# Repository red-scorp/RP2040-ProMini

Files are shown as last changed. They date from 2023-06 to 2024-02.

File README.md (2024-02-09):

```
 ______  ______ ______   ______   __     ______     ______           ______  _       _ 
(_____ \(_____ (_____ \ / __   | / /    / __   |   (_____ \         |  ___ \(_)     (_)
 _____) )_____) )____) ) | //| |/ /____| | //| |___ _____) )___ ___ | | _ | |_ ____  _ 
(_____ (|  ____//_____/| |// | |___   _) |// | (___)  ____/ ___) _ \| || || | |  _ \| |
      | | |     _______|  /__| |   | | |  /__| |   | |   | |  | |_| | || || | | | | | |
      |_|_|    (_______)\_____/    |_|  \_____/    |_|   |_|   \___/|_||_||_|_|_| |_|_|
```

# RP2040-ProMini Project

The RP2040-ProMini project aims to create a replacement for the Arduino Pro Mini using the RP2040 MCU.

## RP2040-ProMini Board

The **RP2040-ProMini** board is a 4-layer board designed to accommodate the popular Raspberry Pi RP2040 MCU in the commonly used, but obsolete, Arduino Pro Mini footprint.

Preview:

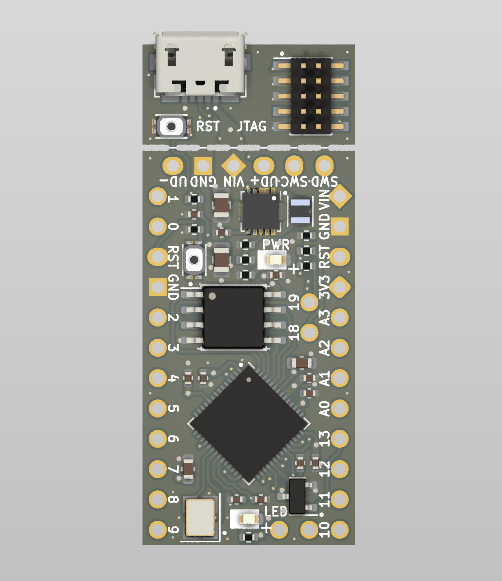
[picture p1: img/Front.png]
RP2040-ProMini Front preview

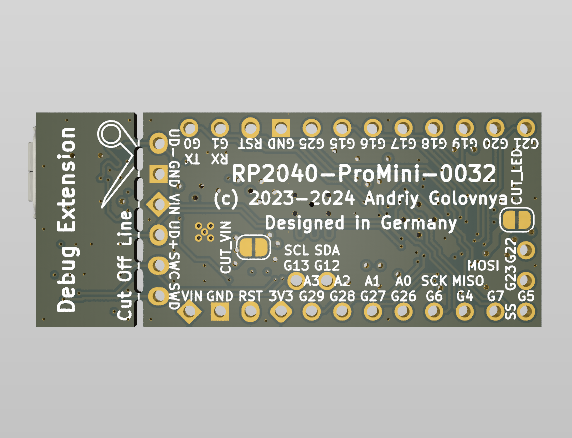
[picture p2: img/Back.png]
RP2040-ProMini Back preview

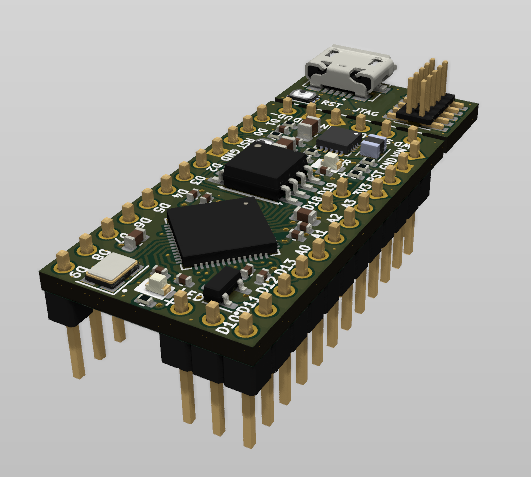
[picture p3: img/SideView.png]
RP2040-ProMini Side View preview


You can view the [Schematics in PDF format](doc/RP2040-ProMini.pdf) for detailed information.

STEP 3D files are available [with pins](doc/RP2040-ProMini-with-pins.step) and [without pins](doc/RP2040-ProMini-board.step).

Features:

- Arduino Pro Mini compatible pinout
- Partially compatible with Arduino Nano RP2040 Connect pinout
- _(v3.x)_ Detachable USB and JTAG extension board with RESET button
- Dual-core Cortex-M0+ Raspberry Pi RP2040
- Small footprint suitable for DIY projects
- _(v1.x)_ 19 GPIO pins, including 4 analog inputs or _(v2.x-v3.x)_ 21 GPIO pins, including 4 analog inputs
- USB data pins on the side connector
- SWD debugging pins on the side connector
- _(v1.x)_ LDO-based 3.3V power supply with a maximum 16V input or _(v2.x-v3.x)_ Buck-Boost converter based 3.3V power supply with input range of 2.5V-12V
- Supports both SOIC and WSON 16MB flash packages
- Flat back side enables use as a sub-assembly
- Two cut points to reduce power consumption of unused components

CAM files, as well as the BOM and CPL files for JLCPCB, are available.

### Board Pinout

Following pinout is used for the board:

| Board Pin | RP2040 Pin | Function | Notes |
| --- | --- | --- | ----- |
| D0 | GPIO1 | UART0 TX | |
| D1 | GPIO0 | UART0 RX | |
| D2 | GPIO25 | | |
| D3 | GPIO15 | | |
| D4 | GPIO16 | | |
| D5 | GPIO17 | | |
| D6 | GPIO18 | | |
| D7 | GPIO19 | | |
| D8 | GPIO20 | | |
| D9 | GPIO21 | | |
| D10 | GPIO5 | SS | |
| D11 | GPIO7 | MOSI | |
| D12 | GPIO4 | MISO | |
| D13 | GPIO6 | SCK | LED |
| D14 A0 | GPIO26 | | |
| D15 A1 | GPIO27 | | |
| D16 A2 | GPIO28 | | |
| D17 A3 | GPIO29 | | |
| D18 | GPIO12 | SDA | |
| D19 | GPIO13 | SCL | |
| D20 | GPIO22 | | |
| D21 | GPIO23 | | |

### Cut Points

There are two cut points on the board to reduce power consumption of unused components.

| Cut Point | Function | Notes |
| --- | --- | ----- |
| CUT_VIN | Separates VIN-to-3V3 power supply with power LED from the rest of the board | This cut point is useful if you want to power the board from 3V3 pin instead of VIN pin. |
| CUT_LED | Separates LED on pin D13 from the rest of the board | This cut point is useful if you want to reduce power consumption of the board. |

## Version History

Roughly RP2040-ProMini board exists in three flavors:

- v1.x - this boards are cheaper because they are based on LDO power supply.
- v2.x - this boards are more expensive because they are based on Buck-Boost power supply.
- v3.x - this boards has same basic design as v2.x but includes detachable USB and JTAG extension board.

The development of v3.x boards is happening in *master* branch, while v1.x and v2.x boards are developed in *dev_v1* and *dev_v2* branches respectively.

Each board version listed below is tagged in its respective branch and includes all the necessary files to manufacture the board.

### v3.2 - 09.02.2024

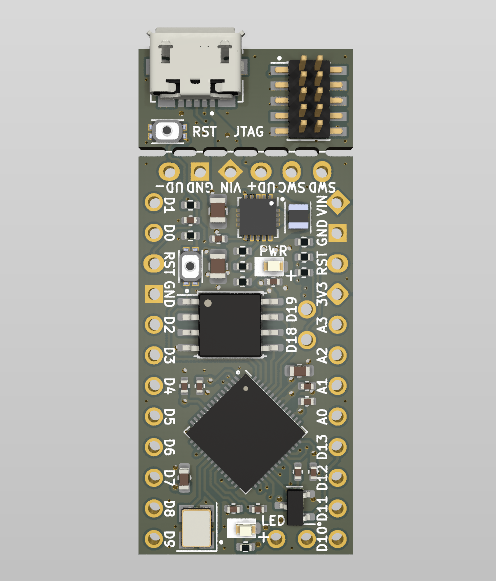
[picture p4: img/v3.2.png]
v3.2 board preview


- Added Gxx pin names on the back of the board.
- Made extension board cut-out openings wider for easier cutting.

### v3.1 - 21.11.2023

v3.1 board preview

- Removed pull-up resistor from SWCLK line.
- Added white silkscreen under LEDs to add light reflection.

### v3.0 - 29.08.2023

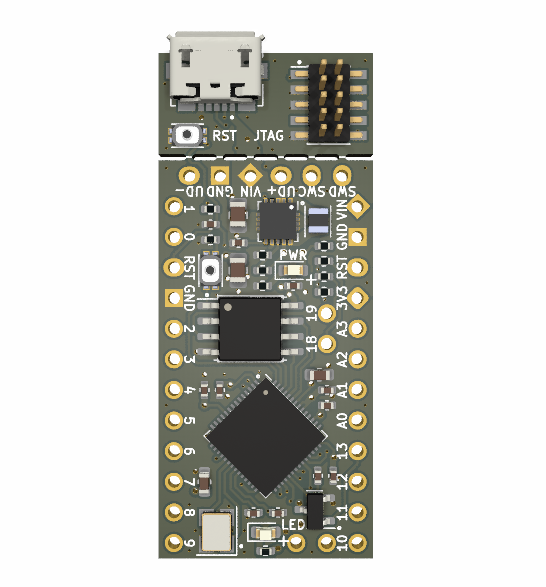
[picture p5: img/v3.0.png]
v3.0 board preview


- Added detachable USB and JTAG extension board with RESET button.
- Improved routing a bit.

### v2.2 - 01.01.2024

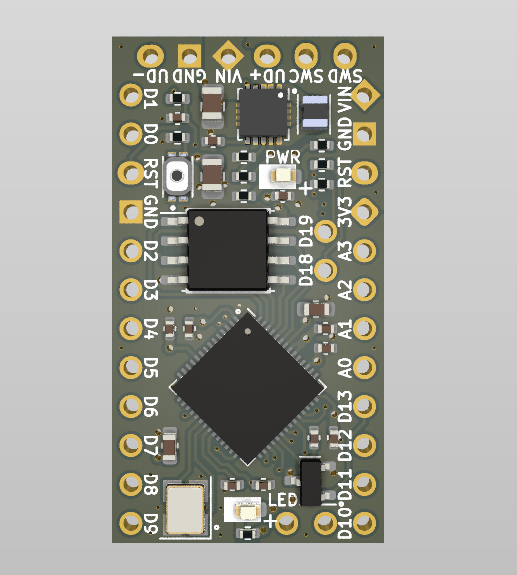
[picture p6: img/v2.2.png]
v2.2 board preview


- Added Gxx pin names on the back of the board.

### v2.1 - 21.11.2023

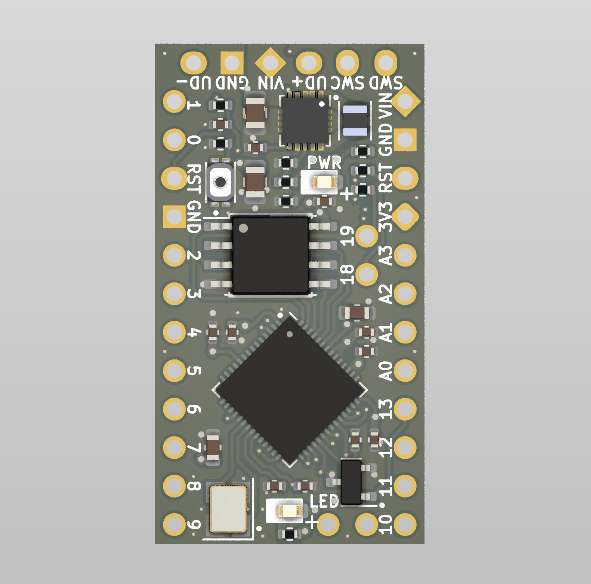
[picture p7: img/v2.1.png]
v2.1 board preview


- Removed pull-up resistor from SWCLK line.
- Added white silkscreen under LEDs to add light reflection.

### v2.0 - 23.07.2023

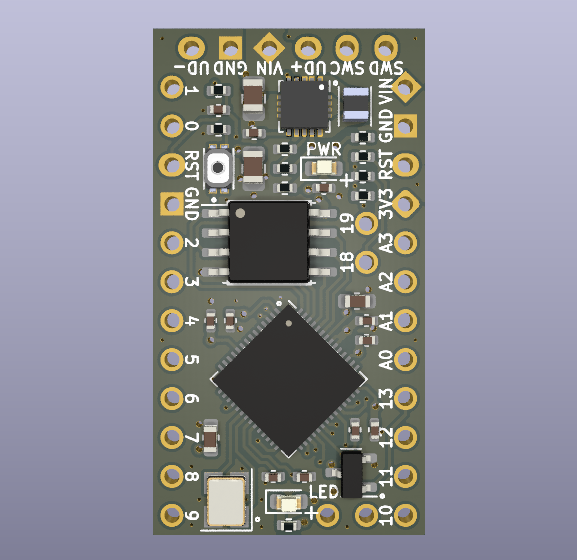
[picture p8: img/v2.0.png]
v2.0 board preview


- Use Buck-Boost converter instead of LDO.
- Added two new digital pins.
- Moved few components around.

### v1.3 - 01.01.2024

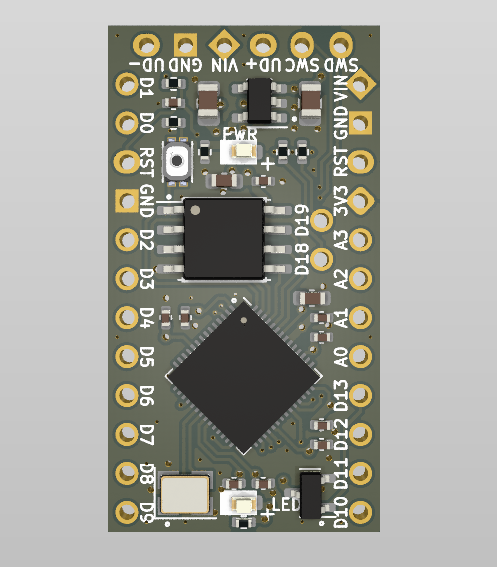
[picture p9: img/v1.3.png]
v1.3 board preview


- Added Gxx pin names on the back of the board.
- Made front and back texts bigger for better readability.

### v1.2 - 21.11.2023

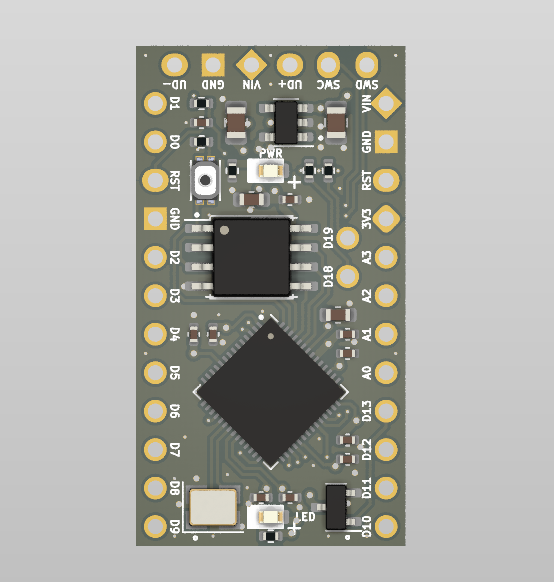
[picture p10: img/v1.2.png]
v1.2 board preview


- Removed pull-up resistor from SWCLK line.
- Added white silkscreen under LEDs to add light reflection.

### v1.1 - 05.07.2023

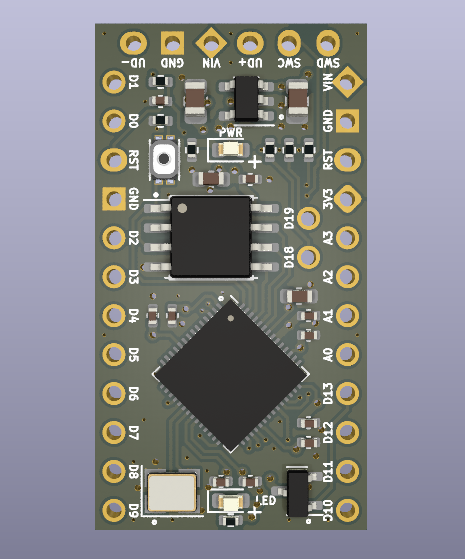
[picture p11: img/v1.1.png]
v1.1 board preview


- Moved few components around.
- Added BOOTSEL mini button for programming convenience.
- Changed LED resistors to allow more current, making LED to emit more light.

### v1.0 - 25.06.2023

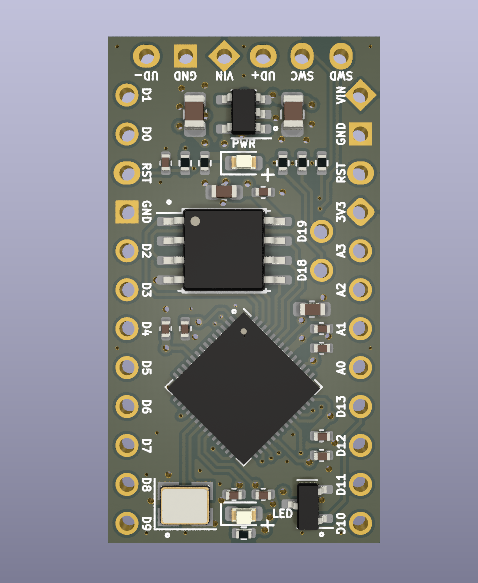
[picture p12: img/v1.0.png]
v1.0 board preview


- Moved few resistors around.
- Added small GND fill under the MCU.
- Switched positions of UD- and GND pins on the side connector.
- Generated different set of BOM and CPL files for SOIC and WSON versions of the board.

### v1.0b1 - 13.06.2023

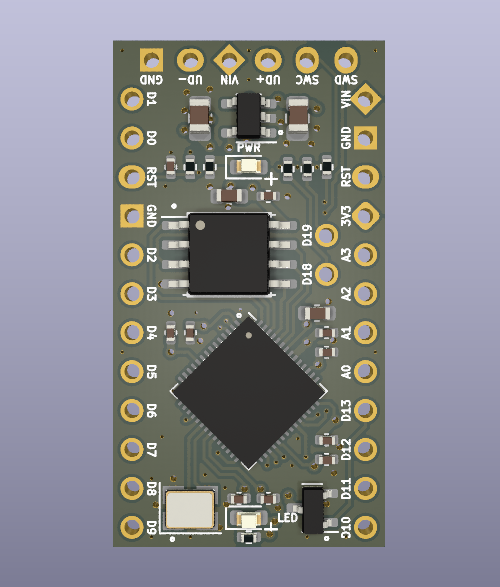
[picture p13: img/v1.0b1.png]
v1.0b1 board preview


Initial release for testing purposes.

## Links

- [Raspberry Pi RP2040 information page](https://www.raspberrypi.com/documentation/microcontrollers/rp2040.html).
- [Arduino Pro Mini information page](https://docs.arduino.cc/retired/boards/arduino-pro-mini).
- [Arduino Nano RP2040 Connect page](https://docs.arduino.cc/hardware/nano-rp2040-connect).
- [Arduino SDK for RP2040 board](https://github.com/earlephilhower/arduino-pico).

## How to Help

Your contributions as code, resources, or finances are welcome! Please contact me directly via email at andriy.golovnya@gmail.com or through my [GitHub profile](https://github.com/red-scorp).

If you'd like to make a financial contribution, you can donate via [PayPal](http://paypal.me/redscorp) or [Ko-Fi](http://ko-fi.com/redscorp). Your support is greatly appreciated.

Thanks in advance!

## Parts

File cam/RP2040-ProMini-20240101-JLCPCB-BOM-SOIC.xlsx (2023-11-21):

Qty | Designator | Footprint | JLCPCB Part# | Comment
2 | C14,C12 | 0805 | C15850 | 10uF
2 | D2,D1 | 0603 | C2286 | RED
11 | C10,C6,C7,C9,C13,C4,C2,C11,C3,C15,C8 | 0402 | C1525 | 100nF
1 | R10 | 0402 | C100271 | 174k
3 | R4,R3,R5 | 0402 | C25744 | 10k
2 | R1,R6 | 0402 | C25905 | 5k1
1 | U1 | SOIC-8-208mil | C97521 | W25Q128JVS
2 | S1,S2 | SMD,1.6x2.6mm | C913786 | 1TS026A-1800-0553-CT
1 | Y1 | SMD3225-4P | C9002 | 12MHz
1 | U2 | LQFN-56(7x7) | C2040 | RP2040
1 | Q1 | SOT-23-3L | C20917 | AO3400A
1 | R7 | 0402 | C11702 | 1k
2 | R8,R9 | 0402 | C279988 | 1M
1 | U3 | WSON-10-EP(3x3) | C48567 | TPS63060
2 | C1,C5 | 0603 | C1604 | 2.2uF
1 | L1 | 0806 | C370025 | 1.5uH
1 | J6 | SMD | C2763165 | USB B micro
1 | J7 | SMD,P=1.27mm | C598540 | JTAG

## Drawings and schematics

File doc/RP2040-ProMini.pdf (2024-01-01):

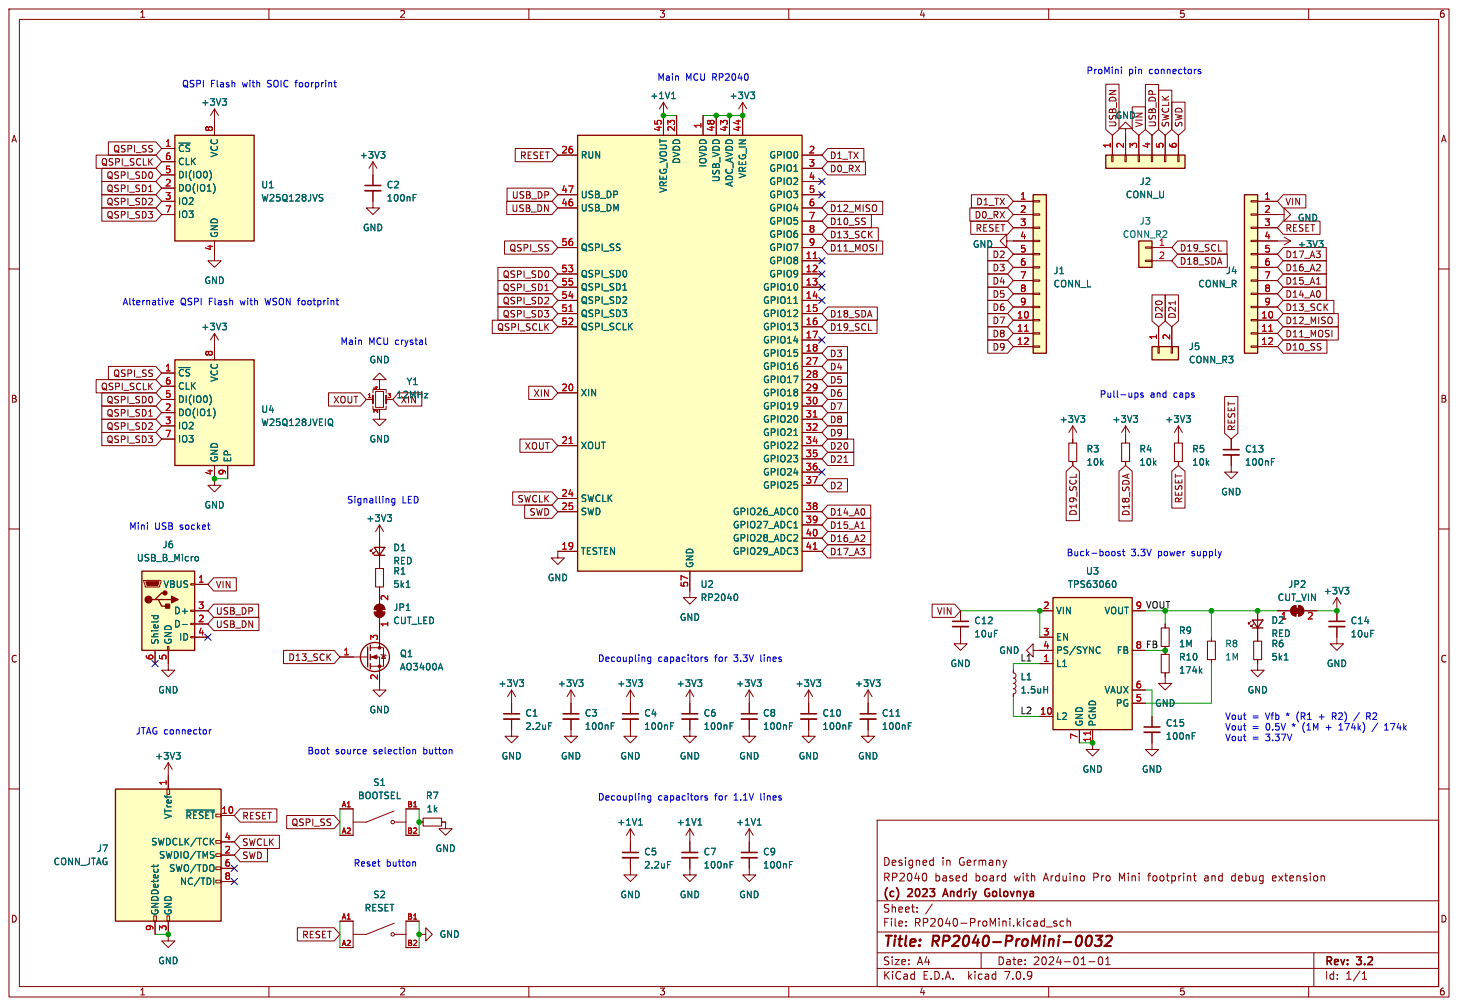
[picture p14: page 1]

1 GPIO8 11 GPIO9 12 GPIO10 13 GPIO11 14 GPIO12 15 GPIO13 16 GPIO14 17 GPIO15 18 TESTEN 19 GPIO0 2 XIN 20 XOUT 21 DVDD 23 SWCLK 24 SWD 25 RUN 26 GPIO16 27 GPIO17 28 GPIO18 29 GPIO1 3 GPIO19 30 GPIO20 31 GPIO21 32 GPIO22 34 GPIO23 35 GPIO24 36 GPIO25 37 GPIO26_ADC0 38 GPIO27_ADC1 39 GPIO2 4 GPIO28_ADC2 40 GPIO29_ADC3 41 ADC_AVDD 43 VREG_IN 44 VREG_VOUT 45 USB_DM 46 USB_DP 47 USB_VDD 48 GPIO3 5 QSPI_SD3 51 QSPI_SCLK 52 QSPI_SD0 53 QSPI_SD2 54 QSPI_SD1 55 QSPI_SS 56 GND 57 GPIO4 6 GPIO5 7 GPIO6 8 GPIO7 9 GND GND

1 GPIO8 11 GPIO9 12 GPIO10 13 GPIO11 14 GPIO12 15 GPIO13 16 GPIO14 17 GPIO15 18 TESTEN 19 GPIO0 2 XIN 20 XOUT 21 DVDD 23 SWCLK 24 SWD 25 RUN 26 GPIO16 27 GPIO17 28 GPIO18 29 GPIO1 3 GPIO19 30 GPIO20 31 GPIO21 32 GPIO22 34 GPIO23 35 GPIO24 36 GPIO25 37 GPIO26_ADC0 38 GPIO27_ADC1 39 GPIO2 4 GPIO28_ADC2 40 GPIO29_ADC3 41 ADC_AVDD 43 VREG_IN 44 VREG_VOUT 45 USB_DM 46 USB_DP 47 USB_VDD 48 GPIO3 5 QSPI_SD3 51 QSPI_SCLK 52 QSPI_SD0 53 QSPI_SD2 54 QSPI_SD1 55 QSPI_SS 56 GND 57 GPIO4 6 GPIO5 7 GPIO6 8 GPIO7 9 U2 RP2040 GND

8 U1 W25Q128JVS GND GND GND GND

Vout = Vfb * (R1 + R2) / R2 Vout = 0.5V * (1M + 174k) / 174k Vout = 3.37V Main MCU crystal
GND

3 SWDCLK/TCK 4 SWO/TDO 6 NC/TDI 8 GNDDetect 9

3 SWDCLK/TCK 4 SWO/TDO 6 NC/TDI 8 GNDDetect 9 GND GND GND

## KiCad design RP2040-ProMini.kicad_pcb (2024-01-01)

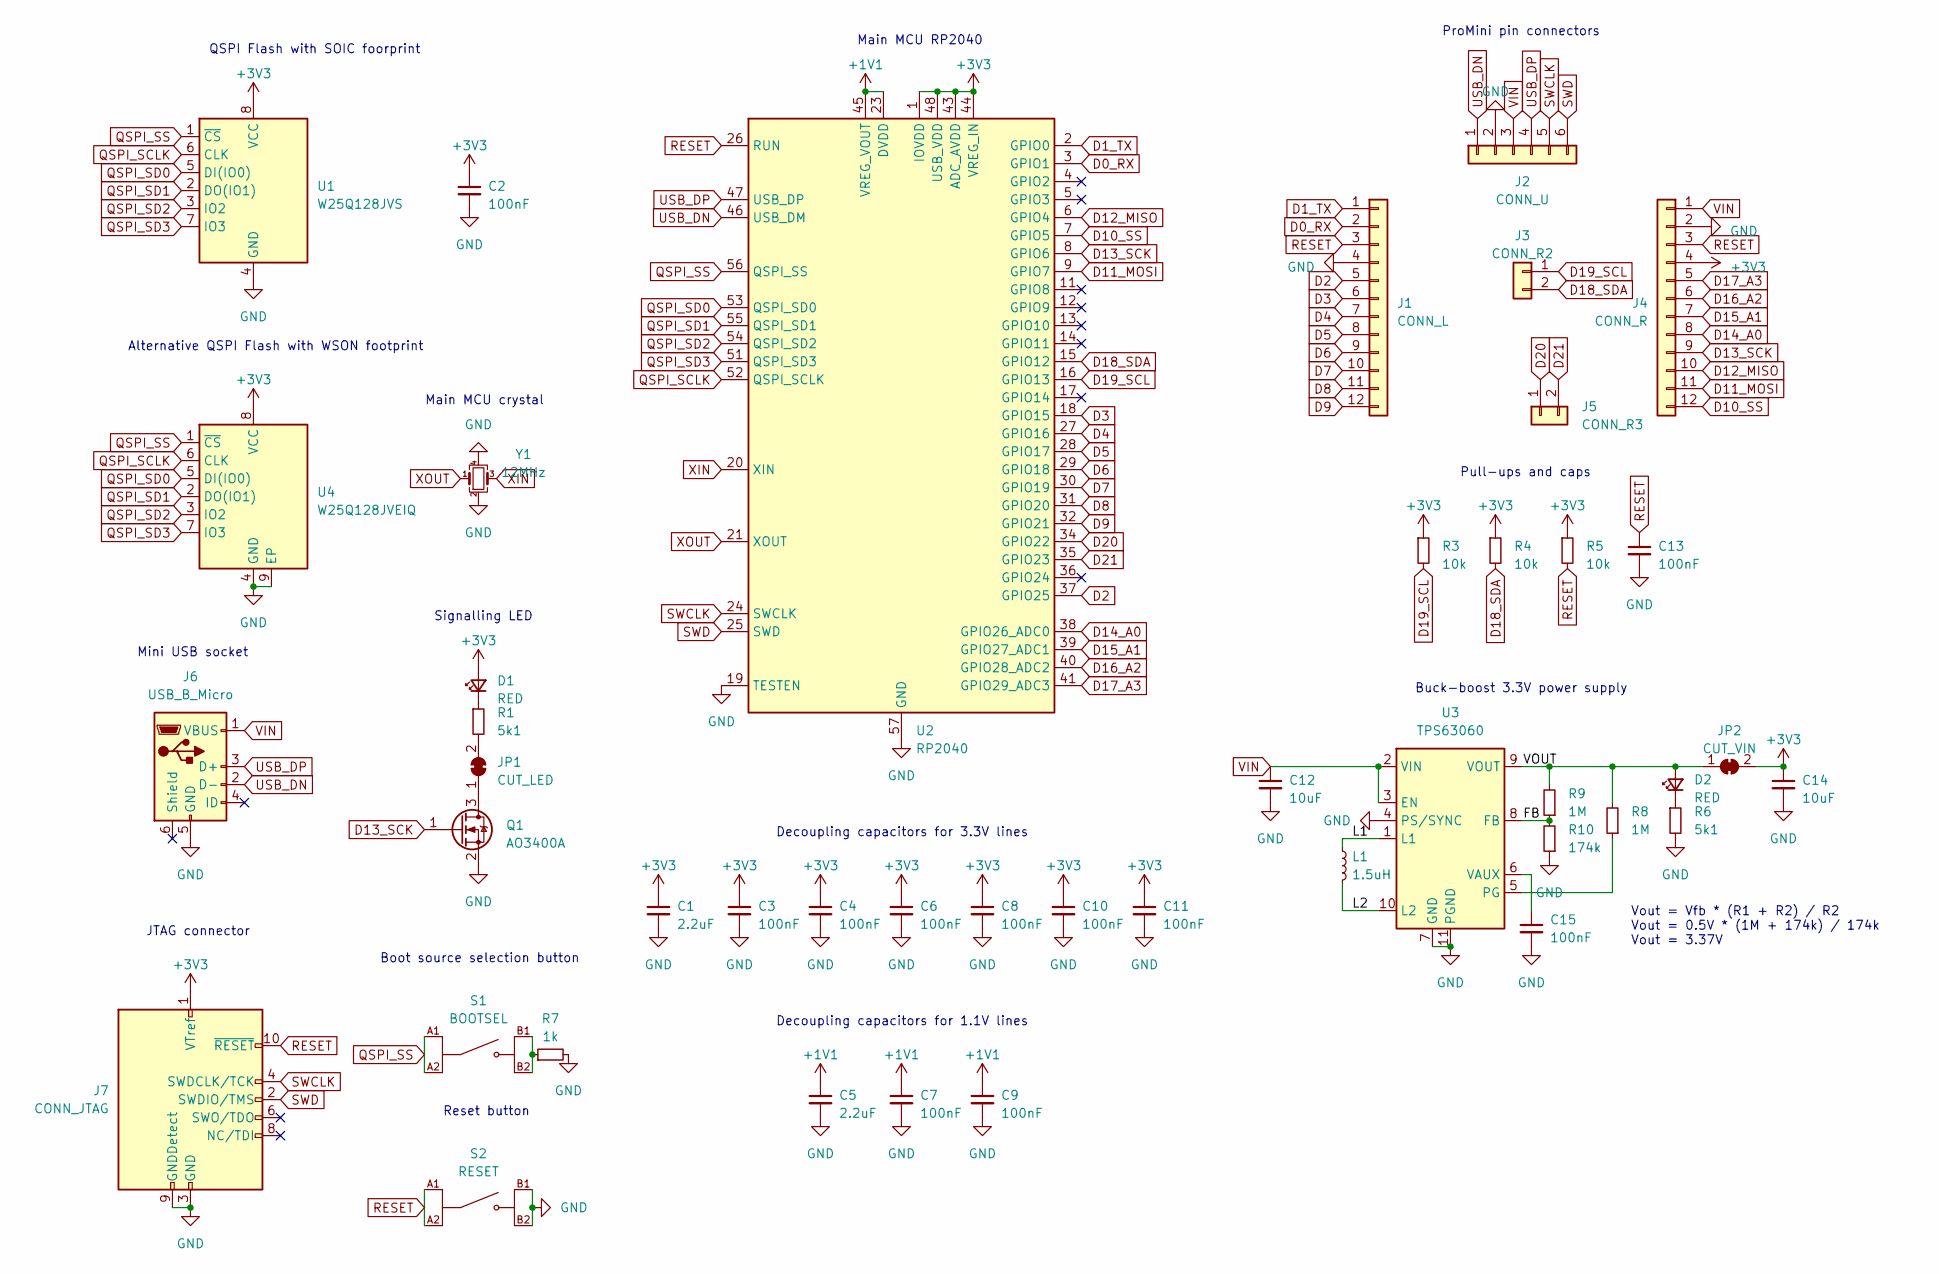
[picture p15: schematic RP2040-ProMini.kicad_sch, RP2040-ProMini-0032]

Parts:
C1, C5: 2.2uF; C_0603_1608Metric
C2, C3, C4, C6, C7, C8, C9, C10, C11, C13, C15: 100nF; C_0402_1005Metric
C12, C14: 10uF; C_0805_2012Metric
D1, D2: RED; LED_0603_1608Metric
J1: CONN_L; PinHeader_1x12_P2.54mm_Vertical
J2: CONN_U; PinHeader_1x06_P2.54mm_Vertical
J3: CONN_R2; PinHeader_1x02_P2.54mm_Vertical
J4: CONN_R; PinHeader_1x12_P2.54mm_Vertical
J5: CONN_R3; PinHeader_1x02_P2.54mm_Vertical
J6: USB_B_Micro; USB_Micro-B_Molex_47346-0001
J7: CONN_JTAG; PinHeader_2x05_P1.27mm_Vertical_SMD
JP1: CUT_LED; SolderJumper-2_P1.3mm_Bridged_RoundedPad1.0x1.5mm
JP2: CUT_VIN; SolderJumper-2_P1.3mm_Bridged_RoundedPad1.0x1.5mm
L1: 1.5uH; L_Murata_DFE201610P
Q1: AO3400A; SOT-23
R1, R6: 5k1; R_0402_1005Metric
R3, R4, R5: 10k; R_0402_1005Metric
R7: 1k; R_0402_1005Metric
R8, R9: 1M; R_0402_1005Metric
R10: 174k; R_0402_1005Metric
S1: BOOTSEL; SW_EVPBB0AAB000; DIGI-KEY_PART_NUMBER P19888CT-ND
S2: RESET; SW_EVPBB0AAB000; DIGI-KEY_PART_NUMBER P19888CT-ND
U1: W25Q128JVS; SOIC-8_5.23x5.23mm_P1.27mm
U2: RP2040; QFN-56-1EP_7x7mm_P0.4mm_EP3.2x3.2mm
U3: TPS63060; Texas_S-PWSON-N10_ThermalVias
U4: W25Q128JVEIQ; WSON-8-1EP_6x5mm_P1.27mm_EP3.4x4.3mm
Y1: 12MHz; Crystal_SMD_3225-4Pin_3.2x2.5mm

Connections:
+1V1: C5.1, C7.1, C9.1, U2.23 (DVDD), U2.45 (VREG_VOUT), U2.50 (DVDD)
+3V3: C1.1, C2.1, C3.1, C4.1, C6.1, C8.1, C10.1, C11.1, C14.1, D1.2 (A), J4.4, J7.1 (VTref), JP2.2 (B), R3.1, R4.1, R5.1, U1.8 (VCC), U2.1 (IOVDD), U2.10 (IOVDD), U2.22 (IOVDD), U2.33 (IOVDD), U2.42 (IOVDD), U2.43 (ADC_AVDD), U2.44 (VREG_IN), U2.48 (USB_VDD), U2.49 (IOVDD), U4.8 (VCC)
/FB: R9.1, R10.2, U3.8 (FB)
/L1: L1.1, U3.1 (L1)
/L2: L1.2, U3.10 (L2)
/VOUT: D2.2 (A), JP2.1 (A), R8.2, R9.2, U3.9 (VOUT)
D0_RX: J1.2, U2.3 (GPIO1)
D1_TX: J1.1, U2.2 (GPIO0)
D2: J1.5, U2.37 (GPIO25)
D3: J1.6, U2.18 (GPIO15)
D4: J1.7, U2.27 (GPIO16)
D5: J1.8, U2.28 (GPIO17)
D6: J1.9, U2.29 (GPIO18)
D7: J1.10, U2.30 (GPIO19)
D8: J1.11, U2.31 (GPIO20)
D9: J1.12, U2.32 (GPIO21)
D10_SS: J4.12, U2.7 (GPIO5)
D11_MOSI: J4.11, U2.9 (GPIO7)
D12_MISO: J4.10, U2.6 (GPIO4)
D13_SCK: J4.9, Q1.1 (G), U2.8 (GPIO6)
D14_A0: J4.8, U2.38 (GPIO26_ADC0)
D15_A1: J4.7, U2.39 (GPIO27_ADC1)
D16_A2: J4.6, U2.40 (GPIO28_ADC2)
D17_A3: J4.5, U2.41 (GPIO29_ADC3)
D18_SDA: J3.2, R4.2, U2.15 (GPIO12)
D19_SCL: J3.1, R3.2, U2.16 (GPIO13)
D20: J5.1, U2.34 (GPIO22)
D21: J5.2, U2.35 (GPIO23)
GND: C1.2, C2.2, C3.2, C4.2, C5.2, C6.2, C7.2, C8.2, C9.2, C10.2, C11.2, C12.2, C13.2, C14.2, C15.2, J1.4, J2.2, J4.2, J6.5 (GND), J7.3 (GND), J7.5 (GND), J7.9 (GNDDetect), Q1.2 (S), R6.2, R7.2, R10.1, S2.B1, S2.B2, U1.4 (GND), U2.19 (TESTEN), U2.57 (GND), U3.4 (PS/SYNC), U3.7 (GND), U3.11 (PGND), U4.4 (GND), U4.9 (EP), Y1.2, Y1.4
unnamed: D1.1 (K), R1.1
unnamed: D2.1 (K), R6.1
unnamed: JP1.1 (A), Q1.3 (D)
unnamed: JP1.2 (B), R1.2
unnamed: R7.1, S1.B1, S1.B2
unnamed: R8.1, U3.5 (PG)
unnamed: C15.1, U3.6 (VAUX)
QSPI_SCLK: U1.6 (CLK), U2.52 (QSPI_SCLK), U4.6 (CLK)
QSPI_SD0: U1.5 (DI(IO0)), U2.53 (QSPI_SD0), U4.5 (DI(IO0))
QSPI_SD1: U1.2 (DO(IO1)), U2.55 (QSPI_SD1), U4.2 (DO(IO1))
QSPI_SD2: U1.3 (IO2), U2.54 (QSPI_SD2), U4.3 (IO2)
QSPI_SD3: U1.7 (IO3), U2.51 (QSPI_SD3), U4.7 (IO3)
QSPI_SS: S1.A1, S1.A2, U1.1 (~CS), U2.56 (QSPI_SS), U4.1 (~CS)
RESET: C13.1, J1.3, J4.3, J7.10 (~RESET), R5.2, S2.A1, S2.A2, U2.26 (RUN)
SWCLK: J2.5, J7.4 (SWDCLK/TCK), U2.24 (SWCLK)
SWD: J2.6, J7.2 (SWDIO/TMS), U2.25 (SWD)
USB_DN: J2.1, J6.2 (D-), U2.46 (USB_DM)
USB_DP: J2.4, J6.3 (D+), U2.47 (USB_DP)
VIN: C12.1, J2.3, J4.1, J6.1 (VBUS), U3.2 (VIN), U3.3 (EN)
XIN: U2.20 (XIN), Y1.3
XOUT: U2.21 (XOUT), Y1.1

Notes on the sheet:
Alternative QSPI Flash with WSON footprint
ProMini pin connectors
Main MCU RP2040
Decoupling capacitors for 3.3V lines
Vout = Vfb * (R1 + R2) / R2 Vout = 0.5V * (1M + 174k) / 174k Vout = 3.37V
Main MCU crystal
Decoupling capacitors for 1.1V lines
Pull-ups and caps
Signalling LED
JTAG connector
Reset button
Mini USB socket
Boot source selection button
Buck-boost 3.3V power supply
QSPI Flash with SOIC foorprint

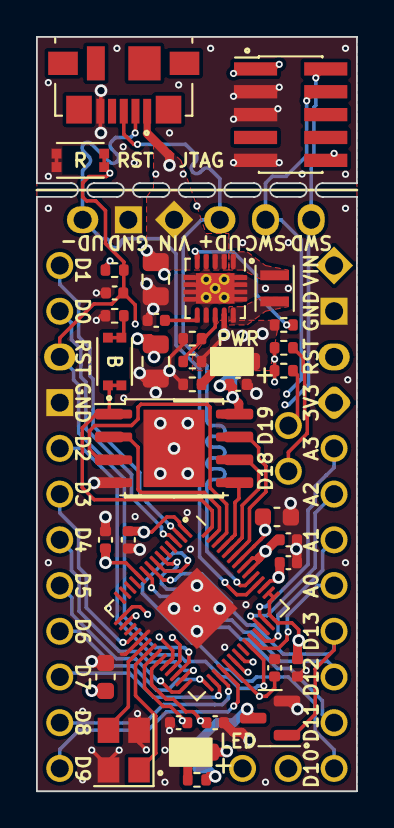
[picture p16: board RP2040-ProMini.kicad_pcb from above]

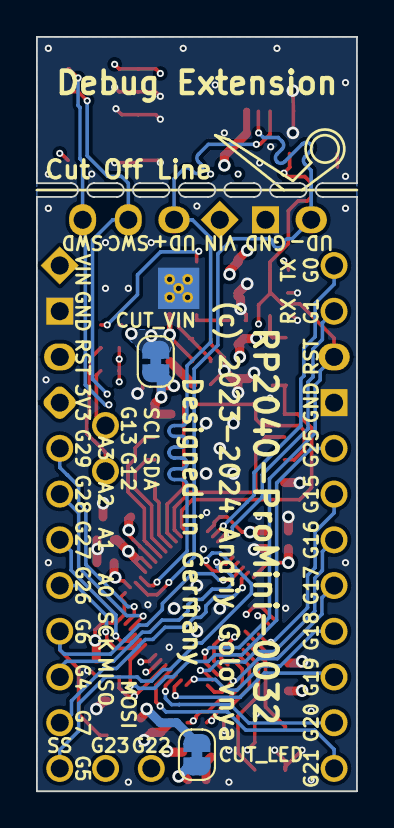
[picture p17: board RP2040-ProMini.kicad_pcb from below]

Board: 4 copper layers, 17.8 x 41.9 mm, 44 parts (7 on the bottom side), 50 nets.

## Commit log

2023-05-31 Initial schematics
    [RP2040-ProMini.kicad_pcb, RP2040-ProMini.kicad_sch]
2023-06-01 Added basic power input
    [RP2040-ProMini.kicad_pcb, RP2040-ProMini.kicad_sch]
2023-06-01 Added whole bunch of things
    [RP2040-ProMini.kicad_pcb, RP2040-ProMini.kicad_sch]
2023-06-02 Removed 2-pin connector. Routed power traces and fills. Started to route traces.
    [RP2040-ProMini.kicad_pcb, RP2040-ProMini.kicad_sch]
2023-06-03 Routed few more traces
    [RP2040-ProMini.kicad_pcb]
2023-06-04 Finished routing of the board.
    [RP2040-ProMini.kicad_pcb, RP2040-ProMini.kicad_sch]
2023-06-05 Optimized routing a bit
    [RP2040-ProMini.kicad_pcb]
2023-06-06 Optimized routing a lot.
    [RP2040-ProMini.kicad_pcb]
2023-06-07 Optimized routing even more.
    [RP2040-ProMini.kicad_pcb]
2023-06-08 Shaped solder areas for non-gpio pins. Added back silkscreen drawings.
    [RP2040-ProMini.kicad_pcb]
2023-06-09 Optimized few traces on PCB. Added few descriptive texts on schematics.
    [RP2040-ProMini.kicad_pcb, RP2040-ProMini.kicad_sch]
2023-06-09 Generated BOM and CPL files
    [RP2040-ProMini-20230609-BOM.xlsx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]
2023-06-09 Generated BOM file
    [RP2040-ProMini-20230609-BOM.xlsx]
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2023-06-10 Fixed USB trace
    [RP2040-ProMini.kicad_pcb]
2023-06-10 Generated CAM files
    [RP2040-ProMini-20230610-BOM.xlsx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]
2023-06-11 Reduced minimum width of fills.
    [RP2040-ProMini.kicad_pcb]
2023-06-11 Added alternative footprint for flash chip
    [RP2040-ProMini.kicad_pcb, RP2040-ProMini.kicad_sch]
2023-06-11 Moved few stuff around.
    [RP2040-ProMini.kicad_pcb]
2023-06-12 Moved some traces around
    [RP2040-ProMini.kicad_pcb]
2023-06-13 Updated release date
    [RP2040-ProMini.kicad_pcb, RP2040-ProMini.kicad_sch]
2023-06-17 Moved few resistors for proper alignment
    [RP2040-ProMini.kicad_pcb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]
2023-06-17 Generated CAM files for SOIC and WSON version of flash chip
    [RP2040-ProMini-20230617-JLCPCB-BOM-SOIC.xlsx, RP2040-ProMini-20230617-JLCPCB-BOM-WSON.xlsx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]
2023-06-22 Switched D- and GND on debug connector. Added missing VIN text.
    [RP2040-ProMini.kicad_pcb, RP2040-ProMini.kicad_sch]
2023-06-24 Changed pads shape after flipping UD- and GND around
    [RP2040-ProMini.kicad_pcb]
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2023-06-24 Added GND plane under the MCU. Generated CAM files.
    [RP2040-ProMini.kicad_pcb]
2023-07-04 Added BOOTSEL button for user convenience
    [RP2040-ProMini.kicad_pcb, RP2040-ProMini.kicad_sch]
2023-07-04 Moved few stuff around for better routing
    [RP2040-ProMini.kicad_pcb]
2023-07-05 Added 3D model for BOOTSEL mini button.
    [EVP-BB4A9B000--3DModel-STEP-56544.STEP, RP2040-ProMini.kicad_pcb]
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2023-07-05 Moved Q1 to the side a bit.
    [RP2040-ProMini.kicad_pcb]
2023-07-05 Generated CAM, BOM and CPL files
    [RP2040-ProMini-20230624-JLCPCB-BOM-SOIC.xlsx, RP2040-ProMini-20230624-JLCPCB-BOM-WSON.xlsx, RP2040-ProMini-20230705-JLCPCB-BOM-SOIC.xlsx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]
2023-07-09 Added buck-boost converter TPS63060 instead of LDO
    [DFE201612E-2R2M=P2.STEP, RP2040-ProMini.kicad_pcb, RP2040-ProMini.kicad_sch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]
2023-07-09 Added D20 and D21. Fixed minor issues. Moved stuff around.
    [RP2040-ProMini.kicad_pcb, RP2040-ProMini.kicad_sch]
2023-07-10 Moved few traces around.
    [RP2040-ProMini.kicad_pcb, RP2040-ProMini.kicad_sch]
2023-07-10 Moved KiCad libraries and 3D file to lib folder
    [RP2040-ProMini.kicad_pcb]
2023-07-12 Moved few traces and vias around.
    [RP2040-ProMini.kicad_pcb]
2023-07-12 Made silkscreen texts bigger for better readability
    [RP2040-ProMini.kicad_pcb]
2023-07-12 Removed drawings on the back side
    [RP2040-ProMini.kicad_pcb]
2023-07-13 Moved few traces and texts around.
    [RP2040-ProMini.kicad_pcb]
2023-07-13 Changed pin number texts, removed D letter
    [RP2040-ProMini.kicad_pcb]
2023-07-13 Rotated quartz for better silk markings alignment
    [RP2040-ProMini.kicad_pcb, RP2040-ProMini.kicad_sch]
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2023-07-13 Moved few stuff around
    [RP2040-ProMini.kicad_pcb]
2023-07-16 Moved few stuff around. Added storage cap.
    [RP2040-ProMini.kicad_pcb, RP2040-ProMini.kicad_sch]
2023-07-16 Moved second row of texts a bit.
    [RP2040-ProMini.kicad_pcb]
2023-07-16 Moved few vias around for better soldering
    [RP2040-ProMini.kicad_pcb]
2023-07-16 Moved few stuff around. Added designed in Germany test.
    [RP2040-ProMini.kicad_pcb]
2023-07-16 Added few descriptive texts on schematics
    [RP2040-ProMini.kicad_sch]
2023-07-17 Aligned schematics components to bigger grid
    [RP2040-ProMini.kicad_sch]
2023-07-23 Removed pins from exports.
    [RP2040-ProMini.kicad_pcb]
2023-08-05 Added removable USB and debug extension board.
    [RP2040-ProMini.kicad_pcb, RP2040-ProMini.kicad_sch]
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2023-08-28 Added link to compatible Arduino SDK. Fixed a typo.
2023-09-01 Moved a power trace a bit.
    [RP2040-ProMini.kicad_pcb]
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2023-11-11 Added white color under the LEDs to add light reflection.
    [RP2040-ProMini.kicad_pcb]
2023-11-21 Removed pull-up resistor for SWDCLK line.
    [RP2040-ProMini.kicad_pcb, RP2040-ProMini.kicad_sch]
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2023-11-22 Made but off gap wider for easier production and use.
    [RP2040-ProMini.kicad_pcb]
2023-12-04 Fixed typo
    [RP2040-ProMini.kicad_pcb, RP2040-ProMini.kicad_sch]
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2023-12-30 Renamed Arduino pins as Dxx. Added GPIO pin names at the back as Gxx.
    [RP2040-ProMini.kicad_pcb]
2024-01-01 Changed board version to 3.2.
    [RP2040-ProMini.kicad_pcb, RP2040-ProMini.kicad_sch]
2024-01-01 Updated copyright year values.
    [RP2040-ProMini.kicad_pcb]

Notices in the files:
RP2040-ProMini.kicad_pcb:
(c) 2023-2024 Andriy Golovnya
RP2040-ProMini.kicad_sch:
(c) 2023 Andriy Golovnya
